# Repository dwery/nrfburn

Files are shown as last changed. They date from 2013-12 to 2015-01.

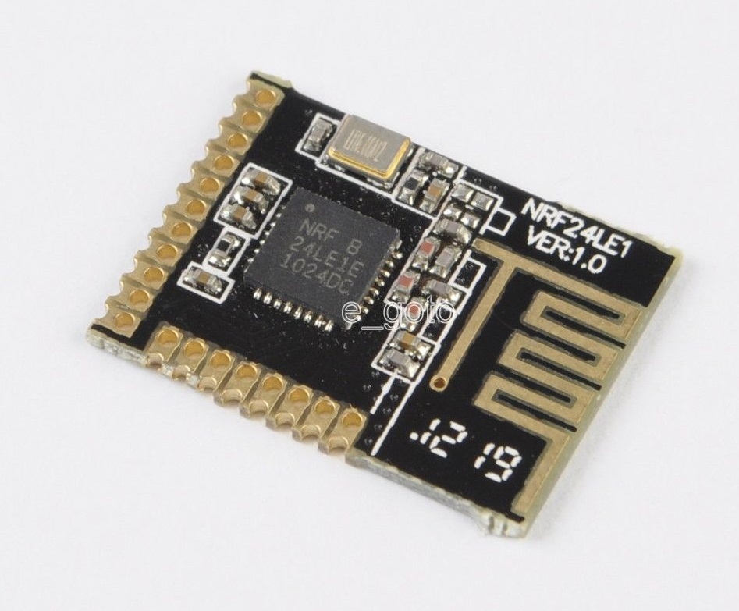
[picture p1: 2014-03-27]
boards/nRF24LE1_small.jpg

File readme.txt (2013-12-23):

This hardware/software package allows full access to the flash area of the Nordic nRF24LU1+ and nRF24LE1 microcontrollers.

The programmer is based on an Atmel ATmega AVR which handles the SPI communication and access to the flash area of the Nordic nRF MCUs. It can erase, write and read the MainBlock and InfoBlock of the nRF flash.

NOTE: Flash read access is only possible if it has been allowed by the nRF InfoPage configuration.

nrfburn can be used to access the flash of "bricked" nRF24LU1+ (both versions: F16 and F32) or nRF24LE1 MCUs. You can reprogram the bootloader or write any other HEX file into the flash area.

Tha programmer hardware is built around an Atmel ATmega88p microcontroller, but ATmega168p or ATmega328p can be used as well. The programmer firmware uses V-USB for communication with the PC. The PCB has breakout footprints compatibile with the SparkFun nRF24LU1+ breakout board, and a generic nRF24LU1+ dongle. This means that you can just plug these breakouts into the programmer to flash the nRF MCU.

Project modules:

AVR circut - Eagle CAD files for the AVR programmer circuit.

firmware - The AVR programmer firmware. It parses requests received from USB and executes SPI commands to access the nRF flash.

nrfburn - PC software which sends commands to the AVR programmer. Written in C++, it is cross-platform and can be compiled with gcc for Linux or Windows (MinGW).

nrfburn is still under active development, and parts of it are not working. It has not yet been tested with nRF24LE1 and problems are expected.

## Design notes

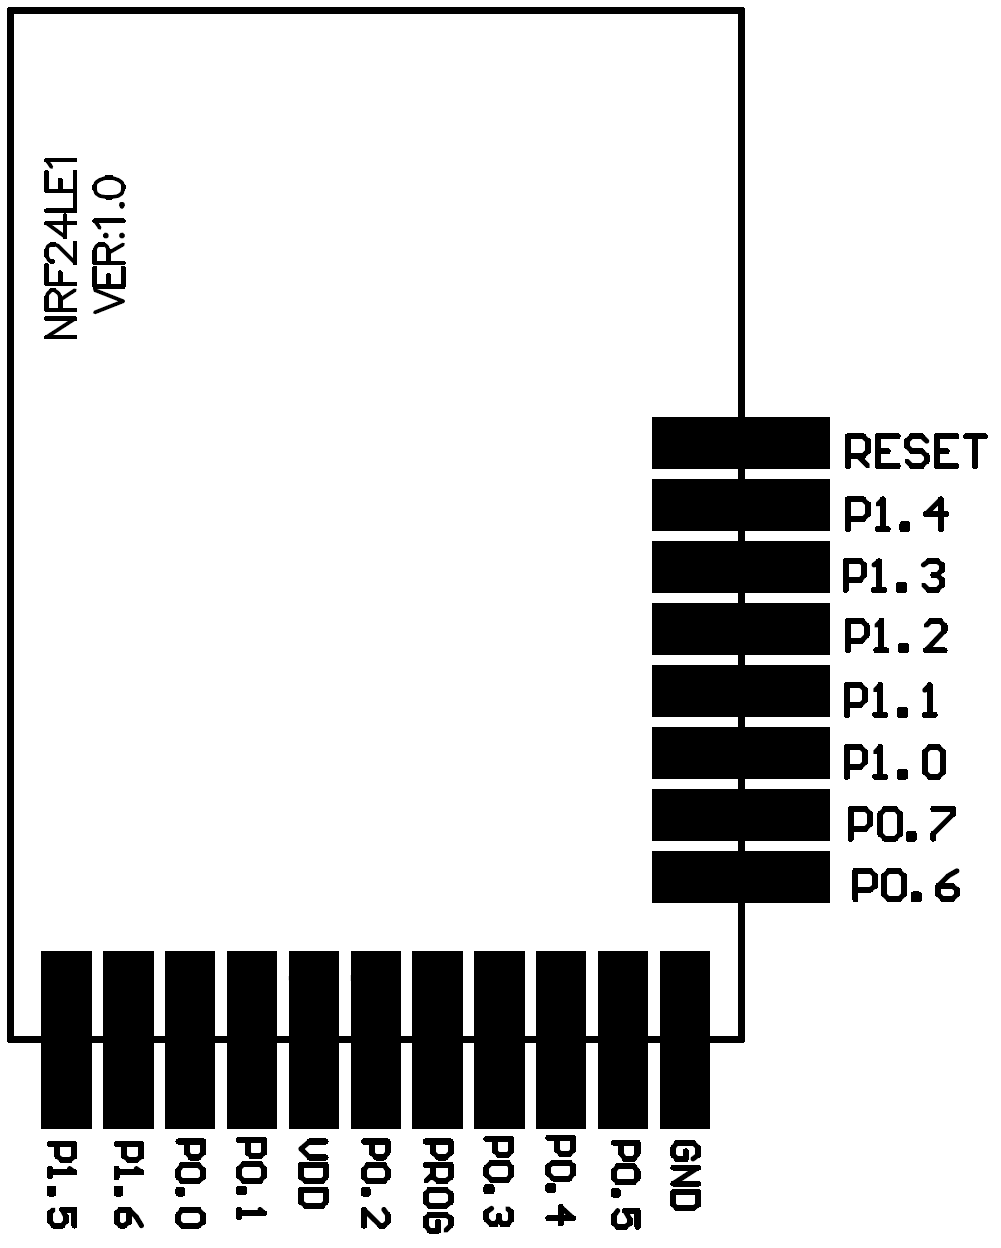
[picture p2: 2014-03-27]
boards/nRF24LE1_small_pinout.png

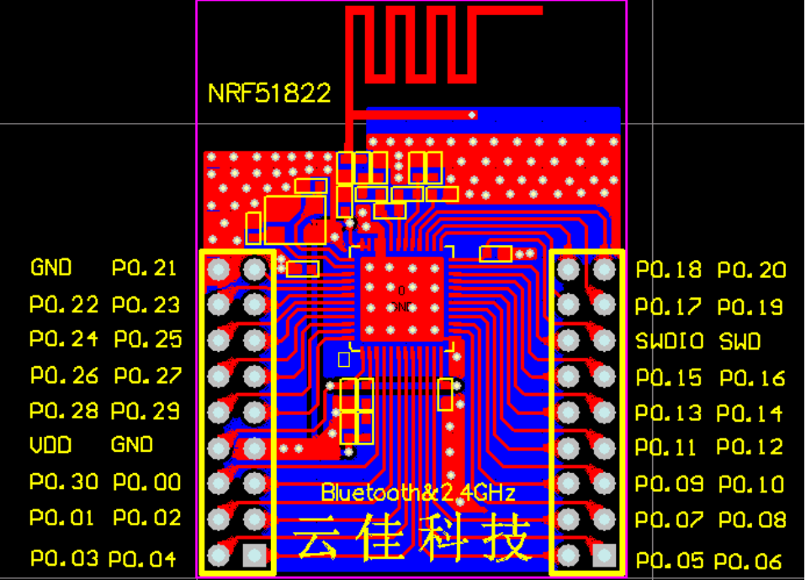
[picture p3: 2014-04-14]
boards/nRF51822.png

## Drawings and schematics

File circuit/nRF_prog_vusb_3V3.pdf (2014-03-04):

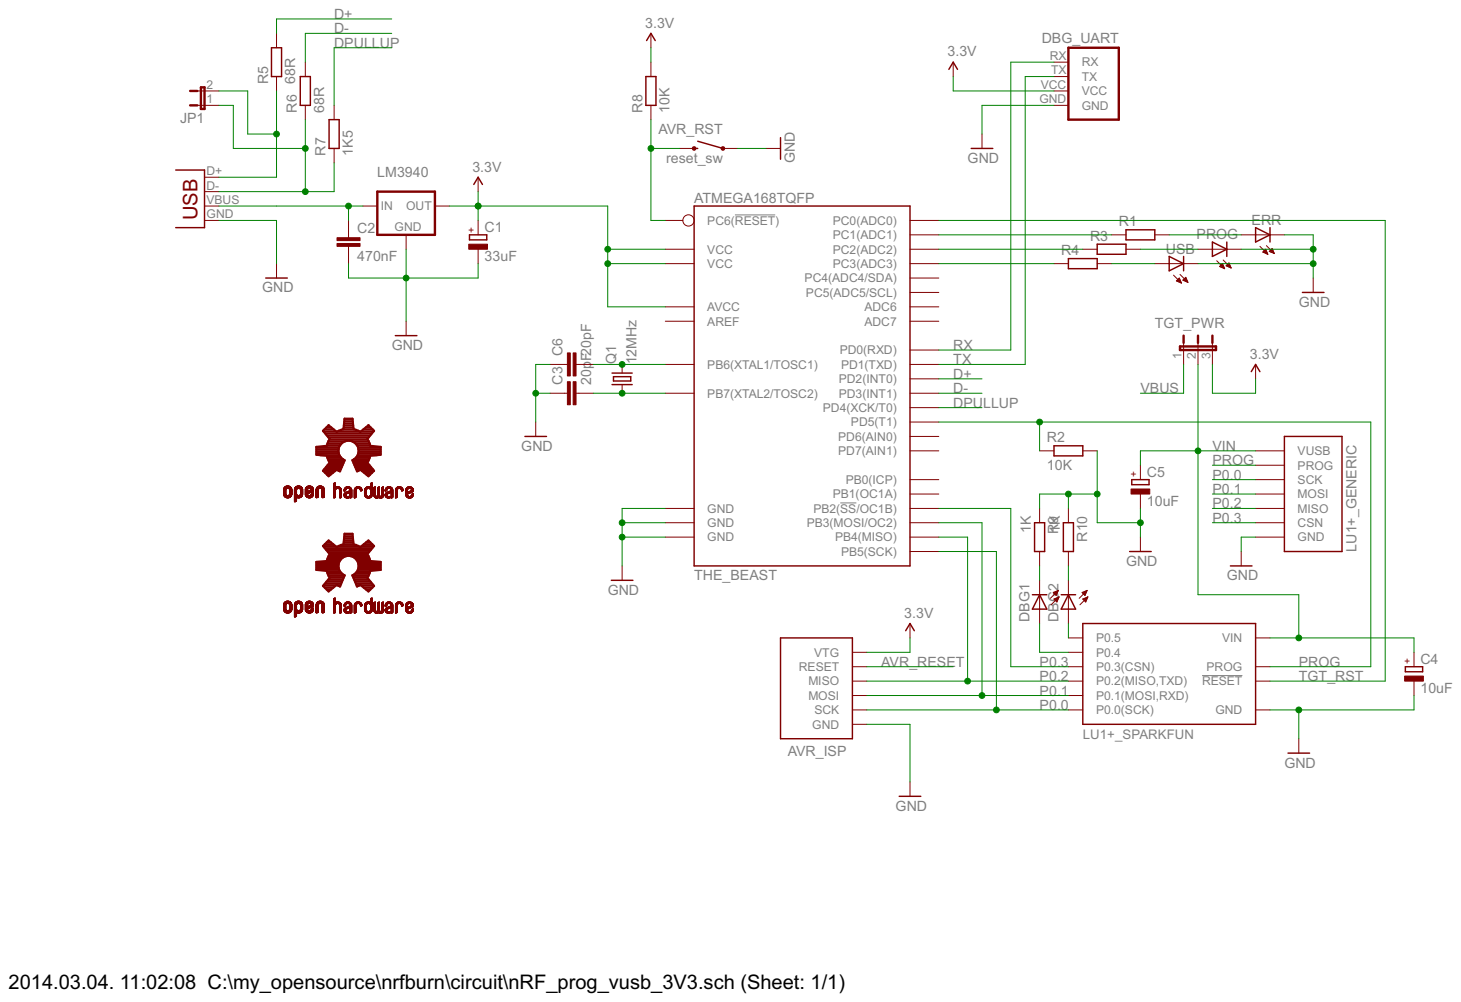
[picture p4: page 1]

2014.03.04. 11:02:08 C:\my_opensource\nrfburn\circuit\nRF_prog_vusb_3V3.sch (Sheet: 1/1)

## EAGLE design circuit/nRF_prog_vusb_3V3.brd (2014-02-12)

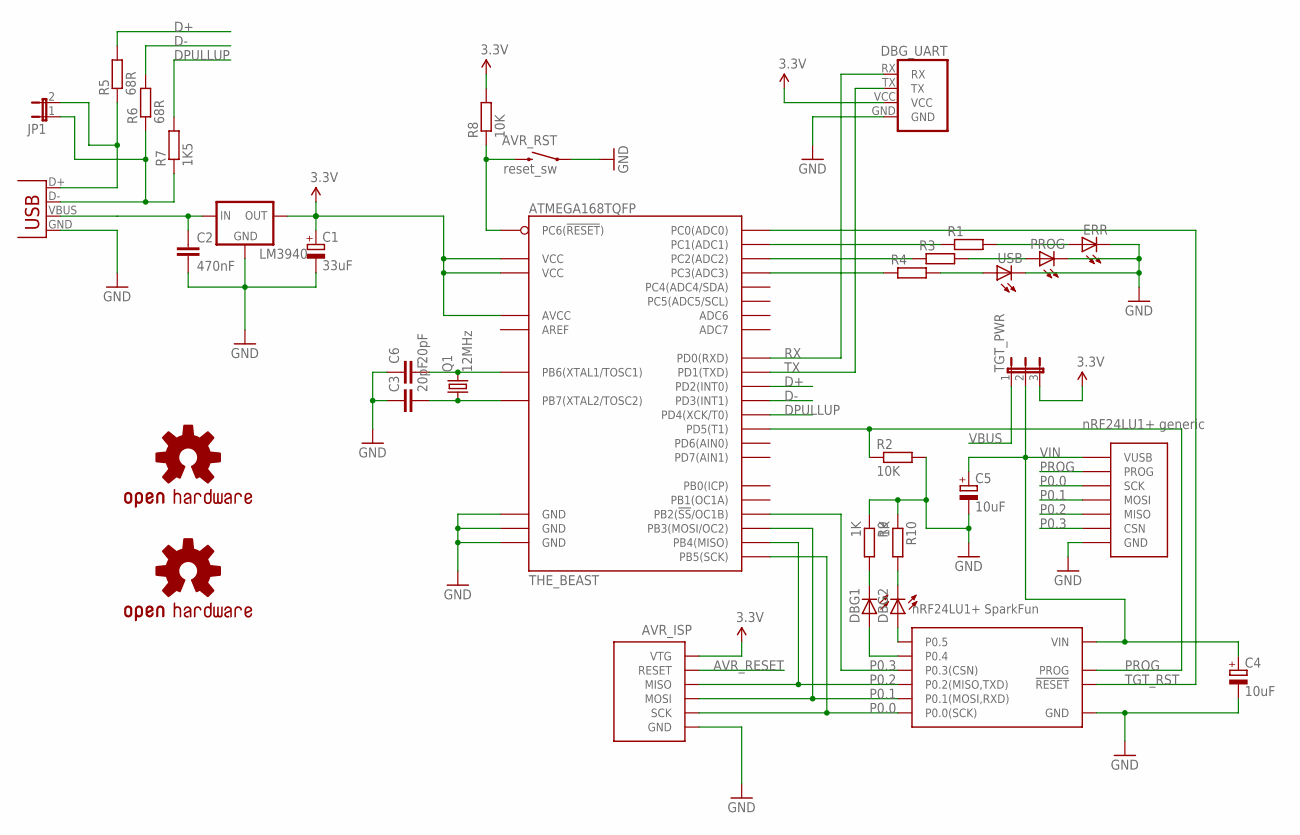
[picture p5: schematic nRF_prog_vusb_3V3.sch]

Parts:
AVR_ISP: AVR-ISP-6SMALL_FP; AVR-ISP-6-SMALL-FP
AVR_RST: reset_sw; TACTILE_SWITCH_SMD
C1: 33uF; SMC_B
C2: 470nF; C0805K
C3, C6: 20pF; C0805
C4, C5: 10uF; SMC_B
DBG1, DBG2: LEDCHIPLED_0805; CHIPLED_0805
DBG_UART: UART_PORT
ERR: LEDCHIPLED_0805; CHIPLED_0805
JP1: JP1E; JP1
LM3940: LM3940; SOT223
LU1+_GENERIC: NRF24LU1P_GENERIC
LU1+_SPARKFUN: NRF24LU1P_SPARKFUN_BREAKOUT; NRF24LU+_SPARKFUN_BREAKOUT
PROG: LEDCHIPLED_0805; CHIPLED_0805
Q1: 12MHz; QUARTZ
R1, R3, R4: R-EU_M0805; M0805
R2, R8: 10K; M0805
R5, R6: 68R; M0805
R7: 1K5; M0805
R9, R10: 1K; M0805
TGT_PWR: JP2E; JP2
THE_BEAST: ATMEGA168TQFP; TQFP32-08
U$1: OSHW-LOGOM; OSHW-LOGO-M
U$2: OSHW-LOGOL; OSHW-LOGO-L
USB: LEDCHIPLED_0805; CHIPLED_0805
USB-B: USBPTH; USB-B-PTH

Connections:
3.3V: AVR_ISP.VCC (VTG), C1.+, DBG_UART.VCC, LM3940.3 (OUT), R8.2, TGT_PWR.3, THE_BEAST.4 (VCC), THE_BEAST.6 (VCC), THE_BEAST.18 (AVCC)
AVR_RESET: AVR_ISP.RESET, AVR_RST.3 (2), R8.1, THE_BEAST.29 (PC6(!RESET!))
D+: R5.2, THE_BEAST.32 (PD2(INT0))
D-: R6.2, THE_BEAST.1 (PD3(INT1))
DPULLUP: R7.2, THE_BEAST.2 (PD4(XCK/T0))
GND: AVR_ISP.GND, AVR_RST.1, C1.-, C2.2, C3.1, C4.-, C5.-, C6.1, DBG_UART.GND, ERR.C, LM3940.2 (GND), LM3940.4 (GND), LU1+_GENERIC.GND, LU1+_SPARKFUN.GND, PROG.C, R2.2, R9.1, R10.1, THE_BEAST.3 (GND), THE_BEAST.5 (GND), THE_BEAST.21 (GND), USB.C, USB-B.GND
unnamed: DBG2.A, LU1+_SPARKFUN.P0.5
unnamed: DBG1.A, LU1+_SPARKFUN.P0.4
unnamed: DBG2.C, R10.2
unnamed: DBG1.C, R9.2
unnamed: R4.1, THE_BEAST.26 (PC3(ADC3))
unnamed: R3.1, THE_BEAST.25 (PC2(ADC2))
unnamed: R1.1, THE_BEAST.24 (PC1(ADC1))
unnamed: R4.2, USB.A
unnamed: PROG.A, R3.2
unnamed: ERR.A, R1.2
unnamed: C6.2, Q1.2, THE_BEAST.7 (PB6(XTAL1/TOSC1))
unnamed: C3.2, Q1.1, THE_BEAST.8 (PB7(XTAL2/TOSC2))
P0.0: AVR_ISP.SCK, LU1+_GENERIC.SCK, LU1+_SPARKFUN.P0.0 (P0.0(SCK)), THE_BEAST.17 (PB5(SCK))
P0.1: AVR_ISP.MOSI, LU1+_GENERIC.MOSI, LU1+_SPARKFUN.P0.1 (P0.1(MOSI,RXD)), THE_BEAST.15 (PB3(MOSI/OC2))
P0.2: AVR_ISP.MISO, LU1+_GENERIC.MISO, LU1+_SPARKFUN.P0.2 (P0.2(MISO,TXD)), THE_BEAST.16 (PB4(MISO))
P0.3: LU1+_GENERIC.CSN, LU1+_SPARKFUN.P0.3 (P0.3(CSN)), THE_BEAST.14 (PB2(!SS!/OC1B))
PROG: LU1+_GENERIC.PROG, LU1+_SPARKFUN.PROG, R2.1, THE_BEAST.9 (PD5(T1))
RX: DBG_UART.RX, THE_BEAST.30 (PD0(RXD))
TGT_RST: LU1+_SPARKFUN.RESET (!RESET!), THE_BEAST.23 (PC0(ADC0))
TX: DBG_UART.TX, THE_BEAST.31 (PD1(TXD))
USB_D+: JP1.2, R5.1, USB-B.D+
USB_D-: JP1.1, R6.1, R7.1, USB-B.D-
VBUS: C2.1, LM3940.1 (IN), TGT_PWR.1, USB-B.VBUS
VIN: C4.+, C5.+, LU1+_GENERIC.VUSB, LU1+_SPARKFUN.VIN, TGT_PWR.2

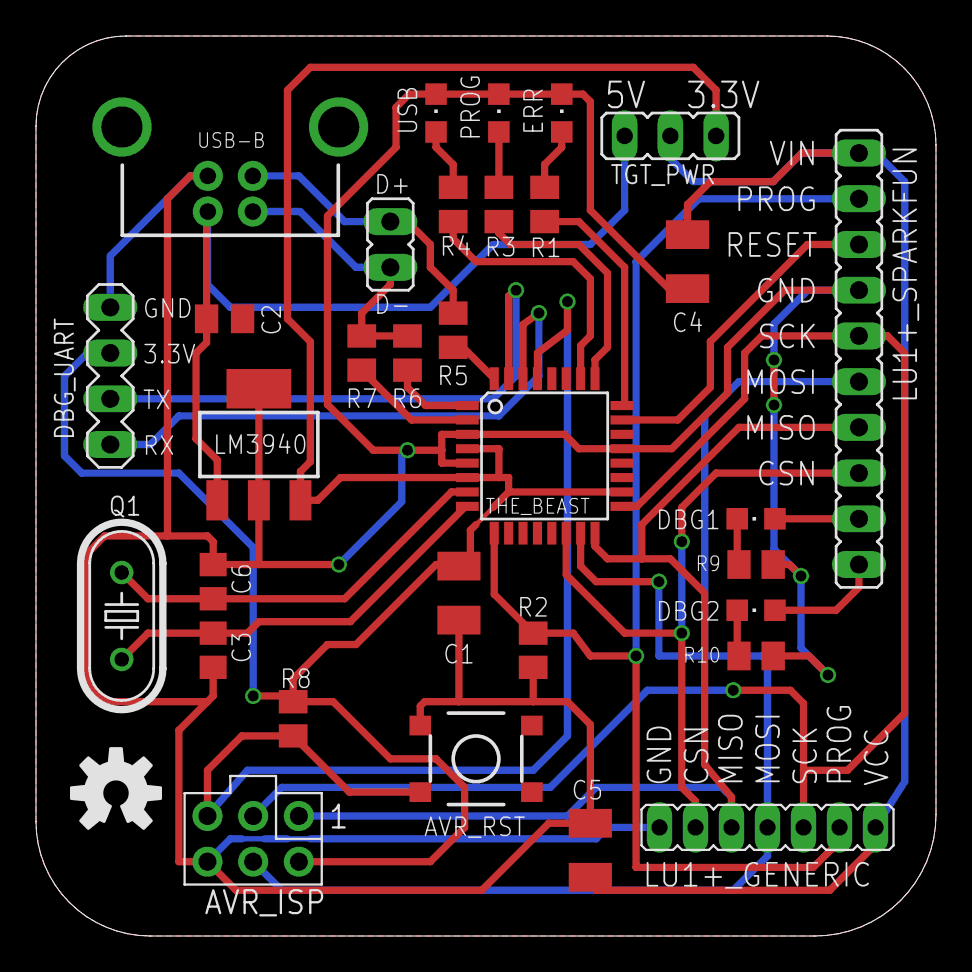
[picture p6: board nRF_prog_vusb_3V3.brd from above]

Board: 2 copper layers, 50.0 x 50.0 mm, 34 parts (1 on the bottom side), 30 nets.

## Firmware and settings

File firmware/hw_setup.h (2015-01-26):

#pragma once

// LEDs
#define LED_ERR_PORT	C
#define LED_ERR_BIT		1

#define LED_PROG_PORT	C
#define LED_PROG_BIT	2

#define LED_USB_PORT	C
#define LED_USB_BIT		3


// the nRF24LU1+ and nRF24LE1 programming interface
#define PROG_PORT		D
#define PROG_BIT		5

#define MOSI_PORT		B
#define MOSI_BIT		3

#define CSN_PORT		B
#define CSN_BIT			2

#define SCK_PORT		B
#define SCK_BIT			5

#define MISO_PORT		B
#define MISO_BIT		4

#define TGT_RST_PORT	C
#define TGT_RST_BIT		0


// the nRF51822 SWD interface (not yet implemented)
#define SWDCLK_PORT		B
#define SWDCLK_BIT		5

#define SWDIO_PORT		B
#define SWDIO_BIT		3

#define SWDCLK_HI()		SetBit(PORT(SWDCLK_PORT), SWDCLK_BIT)
#define SWDCLK_LO()		ClrBit(PORT(SWDCLK_PORT), SWDCLK_BIT)

#define SWDIO_HI()		SetBit(PORT(SWDIO_PORT), SWDIO_BIT)
#define SWDIO_LO()		ClrBit(PORT(SWDIO_PORT), SWDIO_BIT)

#define SWDIO_OUT(pu)	SetBit(DDR(SWDIO_PORT), SWDIO_BIT); pu
#define SWDIO_IN(pu)	ClrBit(DDR(SWDIO_PORT), SWDIO_BIT); pu

#define SWDIO_PU_ON		SWDIO_HI
#define SWDIO_PU_OFF	SWDIO_LO

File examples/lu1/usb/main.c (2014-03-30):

#include <stdbool.h>
#include <stdint.h>
#include <string.h>

#include "reg24lu1.h"
#include "nrfutils.h"

#include "keycode.h"

#include "usb_defs.h"
#include "usb_desc.h"
#include "usb_regs.h"

typedef struct 
{
	uint8_t		keycode;
	uint8_t		modifiers;
} char2keycode_t;

#define MOD_LCTRL	0x01
#define MOD_LSHIFT	0x02

__code const char2keycode_t char2keycode[0x80] = {
	{KC_NO, 0},		// 0x00
	// the next two are special codes for selecting all text in an editor
	// and selecting the current line. this is used for deleting the selected
	// text by 'typing' over it.
	{KC_A, MOD_LCTRL},		// 0x01 ctrl-a
	{KC_HOME, MOD_LSHIFT},	// 0x02 shift-home
	{KC_NO, 0},		// 0x03
	{KC_NO, 0},		// 0x04
	{KC_NO, 0},		// 0x05
	{KC_NO, 0},		// 0x06
	{KC_NO, 0},		// 0x07
	{KC_NO, 0},		// 0x08
	{KC_NO, 0},		// 0x09
	{KC_ENTER, 0},	// 0x0a	\n
	{KC_NO, 0},		// 0x0b
	{KC_NO, 0},		// 0x0c
	{KC_NO, 0},		// 0x0d
	{KC_NO, 0},		// 0x0e
	{KC_NO, 0},		// 0x0f
	{KC_NO, 0},		// 0x10
	{KC_NO, 0},		// 0x11
	{KC_NO, 0},		// 0x12
	{KC_NO, 0},		// 0x13
	{KC_NO, 0},		// 0x14
	{KC_NO, 0},		// 0x15
	{KC_NO, 0},		// 0x16
	{KC_NO, 0},		// 0x17
	{KC_NO, 0},		// 0x18
	{KC_NO, 0},		// 0x19
	{KC_NO, 0},		// 0x1a
	{KC_NO, 0},		// 0x1b
	{KC_NO, 0},		// 0x1c
	{KC_NO, 0},		// 0x1d
	{KC_NO, 0},		// 0x1e
	{KC_NO, 0},		// 0x1f
	{KC_SPACE, 0},	// space
	{KC_1, MOD_LSHIFT},		// !
	{KC_QUOTE, MOD_LSHIFT},	// "
	{KC_3, MOD_LSHIFT},		// #
	{KC_4, MOD_LSHIFT},		// $
	{KC_5, MOD_LSHIFT},		// %
	{KC_7, MOD_LSHIFT},		// &
	{KC_QUOTE, 0},			// '
	{KC_9, MOD_LSHIFT},		// (
	{KC_0, MOD_LSHIFT},		// )
	{KC_KP_ASTERISK, 0},	// *
	{KC_KP_PLUS, 0},		// +
	{KC_COMMA, 0},			// ,
	{KC_KP_MINUS, 0},		// -
	{KC_DOT, 0},			// .
	{KC_KP_SLASH, 0},		// /
	{KC_0, 0},		// 0
	{KC_1, 0},		// 1
	{KC_2, 0},		// 2
	{KC_3, 0},		// 3
	{KC_4, 0},		// 4
	{KC_5, 0},		// 5
	{KC_6, 0},		// 6
	{KC_7, 0},		// 7
	{KC_8, 0},		// 8
	{KC_9, 0},		// 9
	{KC_SCOLON, MOD_LSHIFT},	// :
	{KC_SCOLON, 0},				// ;
	{KC_COMMA, 0},				// <
	{KC_EQUAL, 0},				// =
	{KC_DOT, MOD_LSHIFT},		// >
	{KC_SLASH, MOD_LSHIFT},		// ?
	{KC_2, MOD_LSHIFT},		// @
	{KC_A, MOD_LSHIFT},		// A
	{KC_B, MOD_LSHIFT},		// B
	{KC_C, MOD_LSHIFT},		// C
	{KC_D, MOD_LSHIFT},		// D
	{KC_E, MOD_LSHIFT},		// E
	{KC_F, MOD_LSHIFT},		// F
	{KC_G, MOD_LSHIFT},		// G
	{KC_H, MOD_LSHIFT},		// H
	{KC_I, MOD_LSHIFT},		// I
	{KC_J, MOD_LSHIFT},		// J
	{KC_K, MOD_LSHIFT},		// K
	{KC_L, MOD_LSHIFT},		// L
	{KC_M, MOD_LSHIFT},		// M
	{KC_N, MOD_LSHIFT},		// N
	{KC_O, MOD_LSHIFT},		// O
	{KC_P, MOD_LSHIFT},		// P
	{KC_Q, MOD_LSHIFT},		// Q
	{KC_R, MOD_LSHIFT},		// R
	{KC_S, MOD_LSHIFT},		// S
	{KC_T, MOD_LSHIFT},		// T
	{KC_U, MOD_LSHIFT},		// U
	{KC_V, MOD_LSHIFT},		// V
	{KC_W, MOD_LSHIFT},		// W
	{KC_X, MOD_LSHIFT},		// X
	{KC_Y, MOD_LSHIFT},		// Y
	{KC_Z, MOD_LSHIFT},		// Z
	{KC_LBRACKET, 0},		// [
	{KC_BSLASH, 0},			// backslash
	{KC_RBRACKET, 0},		// ]
	{KC_6, MOD_LSHIFT},		// ^
	{KC_MINUS, MOD_LSHIFT},	// _
	{KC_GRAVE, 0},			// `
	{KC_A, 0},		// a
	{KC_B, 0},		// b
	{KC_C, 0},		// c
	{KC_D, 0},		// d
	{KC_E, 0},		// e
	{KC_F, 0},		// f
	{KC_G, 0},		// g
	{KC_H, 0},		// h
	{KC_I, 0},		// i
	{KC_J, 0},		// j
	{KC_K, 0},		// k
	{KC_L, 0},		// l
	{KC_M, 0},		// m
	{KC_N, 0},		// n
	{KC_O, 0},		// o
	{KC_P, 0},		// p
	{KC_Q, 0},		// q
	{KC_R, 0},		// r
	{KC_S, 0},		// s
	{KC_T, 0},		// t
	{KC_U, 0},		// u
	{KC_V, 0},		// v
	{KC_W, 0},		// w
	{KC_X, 0},		// x
	{KC_Y, 0},		// y
	{KC_Z, 0},		// z
	{KC_LBRACKET, MOD_LSHIFT},	// {
	{KC_BSLASH, MOD_LSHIFT},	// |
	{KC_RBRACKET, MOD_LSHIFT},	// }
	{KC_GRAVE, MOD_LSHIFT},		// ~
	{KC_DELETE, 0},				// 0x7f
};

uint8_t get_keycode_for_char(char c)
{
	uint8_t ndx = c & 0x7f;
	return char2keycode[ndx].keycode;
}

uint8_t get_modifiers_for_char(char c)
{
	uint8_t ndx = c & 0x7f;
	return char2keycode[ndx].modifiers;
}

void main()
{
	bool reportPending = false;
	__code const char* msg = "This is a message that the keyboard will type when scroll lock is activated.";
	__code const char* pMsg = msg;
	uint8_t prev_keycode = KC_NO;
	
	P0DIR = 0x00;	// all outputs
	P0ALT = 0x00;	// all GPIO default behavior

	usbInit();
	
	memset(&kbdReport, 0, sizeof kbdReport);

	for (;;)
	{
		usbPoll();	// handles USB interrupts

		// make a keyboard report
		if (!reportPending  &&  (usbLEDReport & SCROLL_LOCK_MASK) != 0  &&  pMsg)
		{
			char c = *pMsg;

			// get the next char from the stored text message
			uint8_t new_keycode = get_keycode_for_char(c);

			memset(&kbdReport, 0, sizeof kbdReport);	// reset the report
			
			// if the keycode is different than the previous
			// otherwise just send an empty report to simulate key went up
			if (new_keycode != prev_keycode  ||  new_keycode == KC_NO)
			{
				kbdReport.keys[0] = new_keycode;
				kbdReport.modifiers = get_modifiers_for_char(c);

				if (*pMsg == '\0')
					pMsg = NULL;
				else
					++pMsg;
			} else {
				new_keycode = KC_NO;
			}

			prev_keycode = new_keycode;		// remember for later

			reportPending = true;
		} else if ((usbLEDReport & SCROLL_LOCK_MASK) == 0) {
			pMsg = msg;		// rearm for next scroll lock
		}

		// send the report if the endpoint is not busy
		if ((in1cs & 0x02) == 0   &&   (reportPending  ||  usbHasIdleElapsed()))
		{
			// copy the keyboard report into the endpoint buffer
			in1buf[0] = kbdReport.modifiers;
			in1buf[1] = 0;
			in1buf[2] = kbdReport.keys[0];
			in1buf[3] = kbdReport.keys[1];
			in1buf[4] = kbdReport.keys[2];
			in1buf[5] = kbdReport.keys[3];
			in1buf[6] = kbdReport.keys[4];
			in1buf[7] = kbdReport.keys[5];

			// send the data on it's way
			in1bc = 8;
			
			reportPending = false;
		}
	}
}

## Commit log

2013-12-23 labels and messages fix
    [main.cpp]
2013-12-29 New version works uses reset which hopefully fixes the problems with programming nRF24LU1+ It looks like it is necessary to reset the target before and/or after programming.
    [nRF_prog_vusb_3V3.brd, nRF_prog_vusb_3V3.sch]
2014-01-20 read InfoPage now works correctly
    [main.cpp]
2014-02-03 added testpins for USB
    [nRF_prog_vusb_3V3.brd, nRF_prog_vusb_3V3.sch]
2014-02-08 Added precompiled LU1+ bootloader HEX files. Fixed writing to flash.
    [main.cpp]
2014-03-04 added circuit schematic in PDF
    [nRF_prog_vusb_3V3.sch]
2014-03-16 Cleaned up the LED references. USB configuration LED is now working.
2014-10-20 fixed flash size warning
    [main.cpp]

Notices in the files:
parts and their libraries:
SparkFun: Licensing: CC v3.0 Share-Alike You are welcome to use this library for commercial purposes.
